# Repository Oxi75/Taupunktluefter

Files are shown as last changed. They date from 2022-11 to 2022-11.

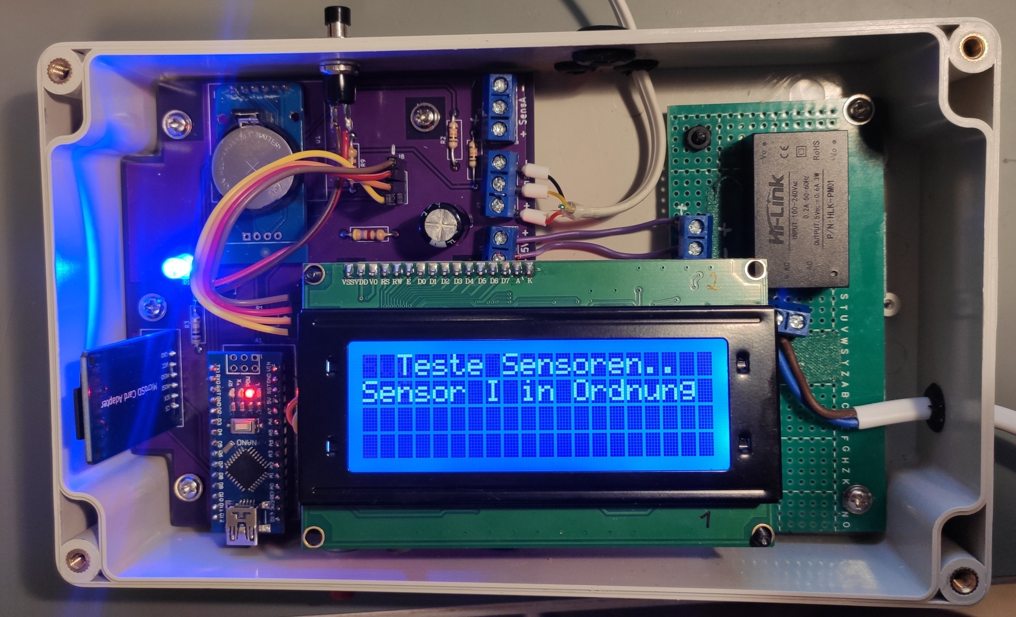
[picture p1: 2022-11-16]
documentation/Housing2.jpg

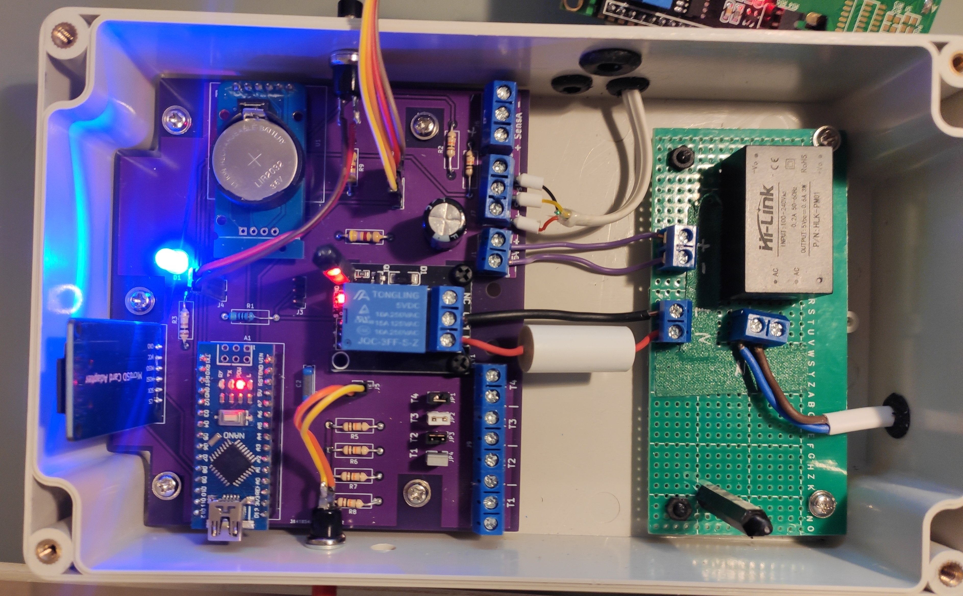
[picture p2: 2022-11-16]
documentation/Housing.jpg

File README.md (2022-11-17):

Dies ist meine erweiterte Version vom Taupunktlüfter mit Logging-Funktion der Maker Media GmbH.
Das Original mit den wichtigsten Fragen rund um den Taupunktlüfter beantwortet eine **[FAQ](https://heise.de/-6526328)**. Die vollständigen Artikel zum Projekt gibt es in der **[Make-Ausgabe 1/22 ab Seite 22](https://www.heise.de/select/make/2022/1/2135511212557842576)** und in der **[Make-Ausgabe 2/22 ab Seite 82](https://www.heise.de/select/make/2022/2/2204711461516715363)** zu lesen.

Das Original Github Projekt liegt hier: https://github.com/MakeMagazinDE/Taupunktluefter

# Taupunktlüfter mit Datenlogger V3.0

* Unterstützung von bis zu vier Tür-Sensoren. D.h. wenn der entsprechende Sensor
anzeigt, dass die Tür nicht geschlossen ist, springt auch der Lüfter nicht an.
Als Sensoren können einfache Schließer (z.B. Magnetschalter) zum Einsatz kommen.
Schalter geschlossen, bedeutet Tür geschlossen.
Auf dem PCB sind Jumper vorgesehen um die Schalter zu überbrücken.
Wird eine offene Tür erkannt, so geht einerseits die Hinweis-LED permanent an,
andererseits wird eine entsprechende Information auf dem Display ausgegeben.
* Display-Auto-Off
Das Backlight des Displays wird nach einer bestimmten Zeit deaktiviert. Um es wieder zu
aktivieren, ist ein dafür vorgesehener Taster zu drücken.
* Umbenennung der Sensoren
„Sensor 1“ und „Sensor 2“ wurden umbenannt nach „Sensor I“ für „Sensor innen“ und
„Sensor A“ für „Sensor außen“.
* Erstellung von Schaltplan und Layout in KiCad 6.0;
Platine passend für Gehäuse Maße: 200 x 120 x 57 mm Deckel klar
https://www.ebay.de/itm/312566082994?var=611287841843

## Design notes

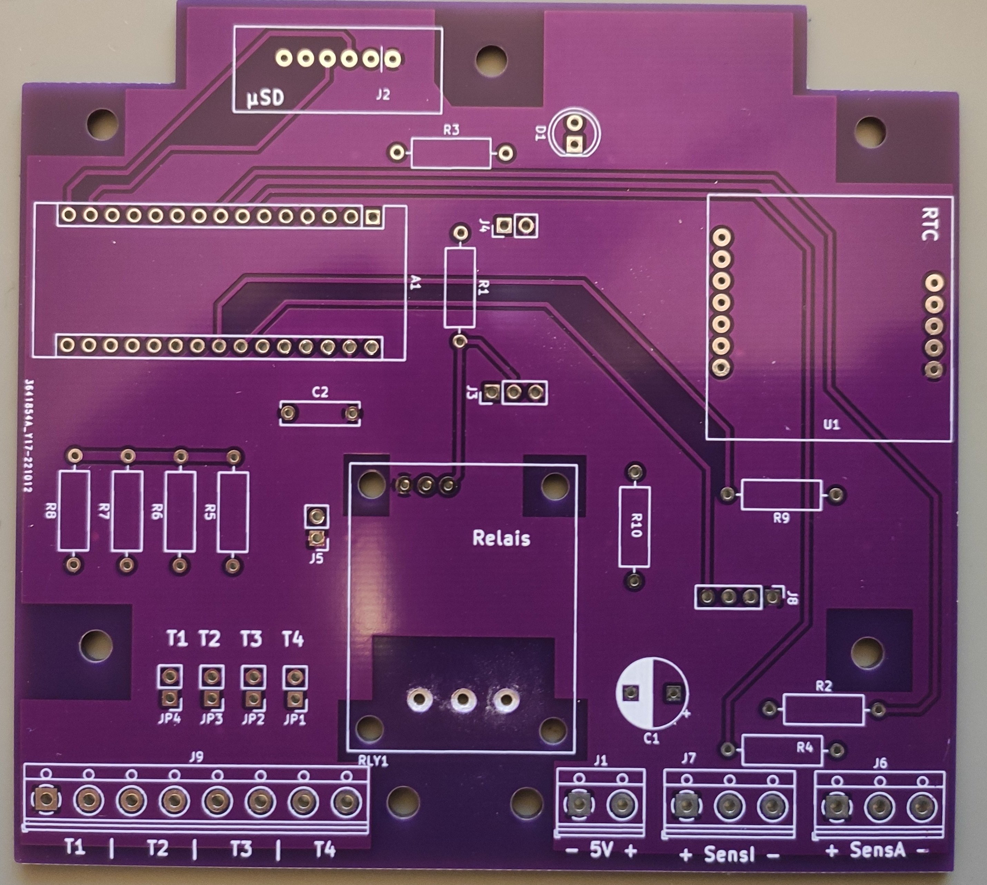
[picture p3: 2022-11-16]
documentation/Taupunkt_PCB_Front.jpg

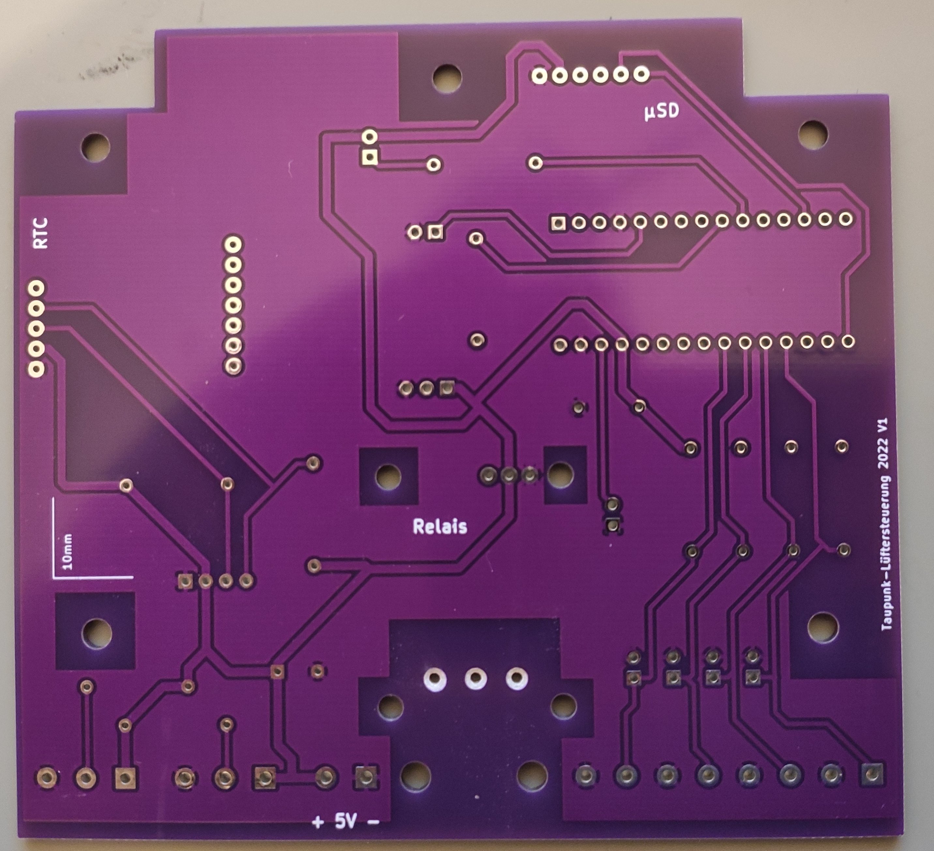
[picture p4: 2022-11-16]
documentation/Taupunkt_PCB_Back.jpg

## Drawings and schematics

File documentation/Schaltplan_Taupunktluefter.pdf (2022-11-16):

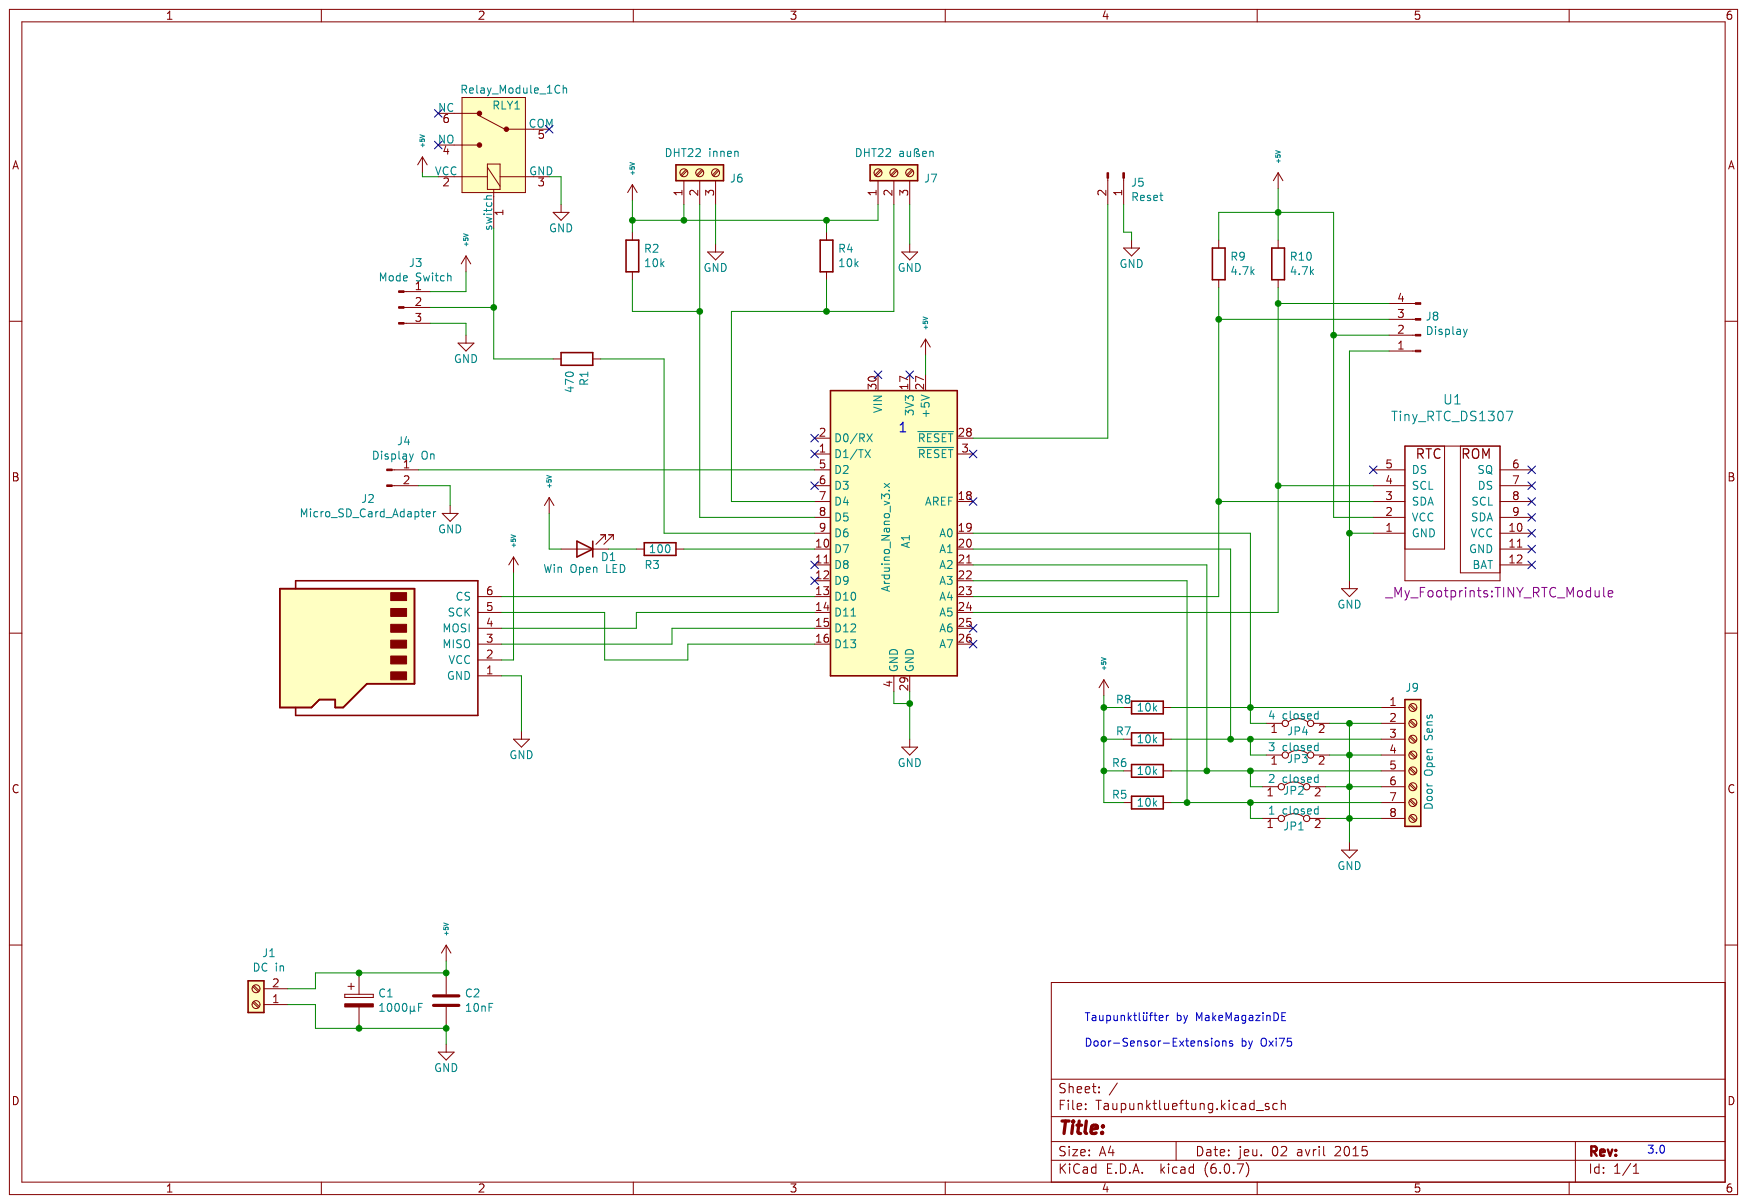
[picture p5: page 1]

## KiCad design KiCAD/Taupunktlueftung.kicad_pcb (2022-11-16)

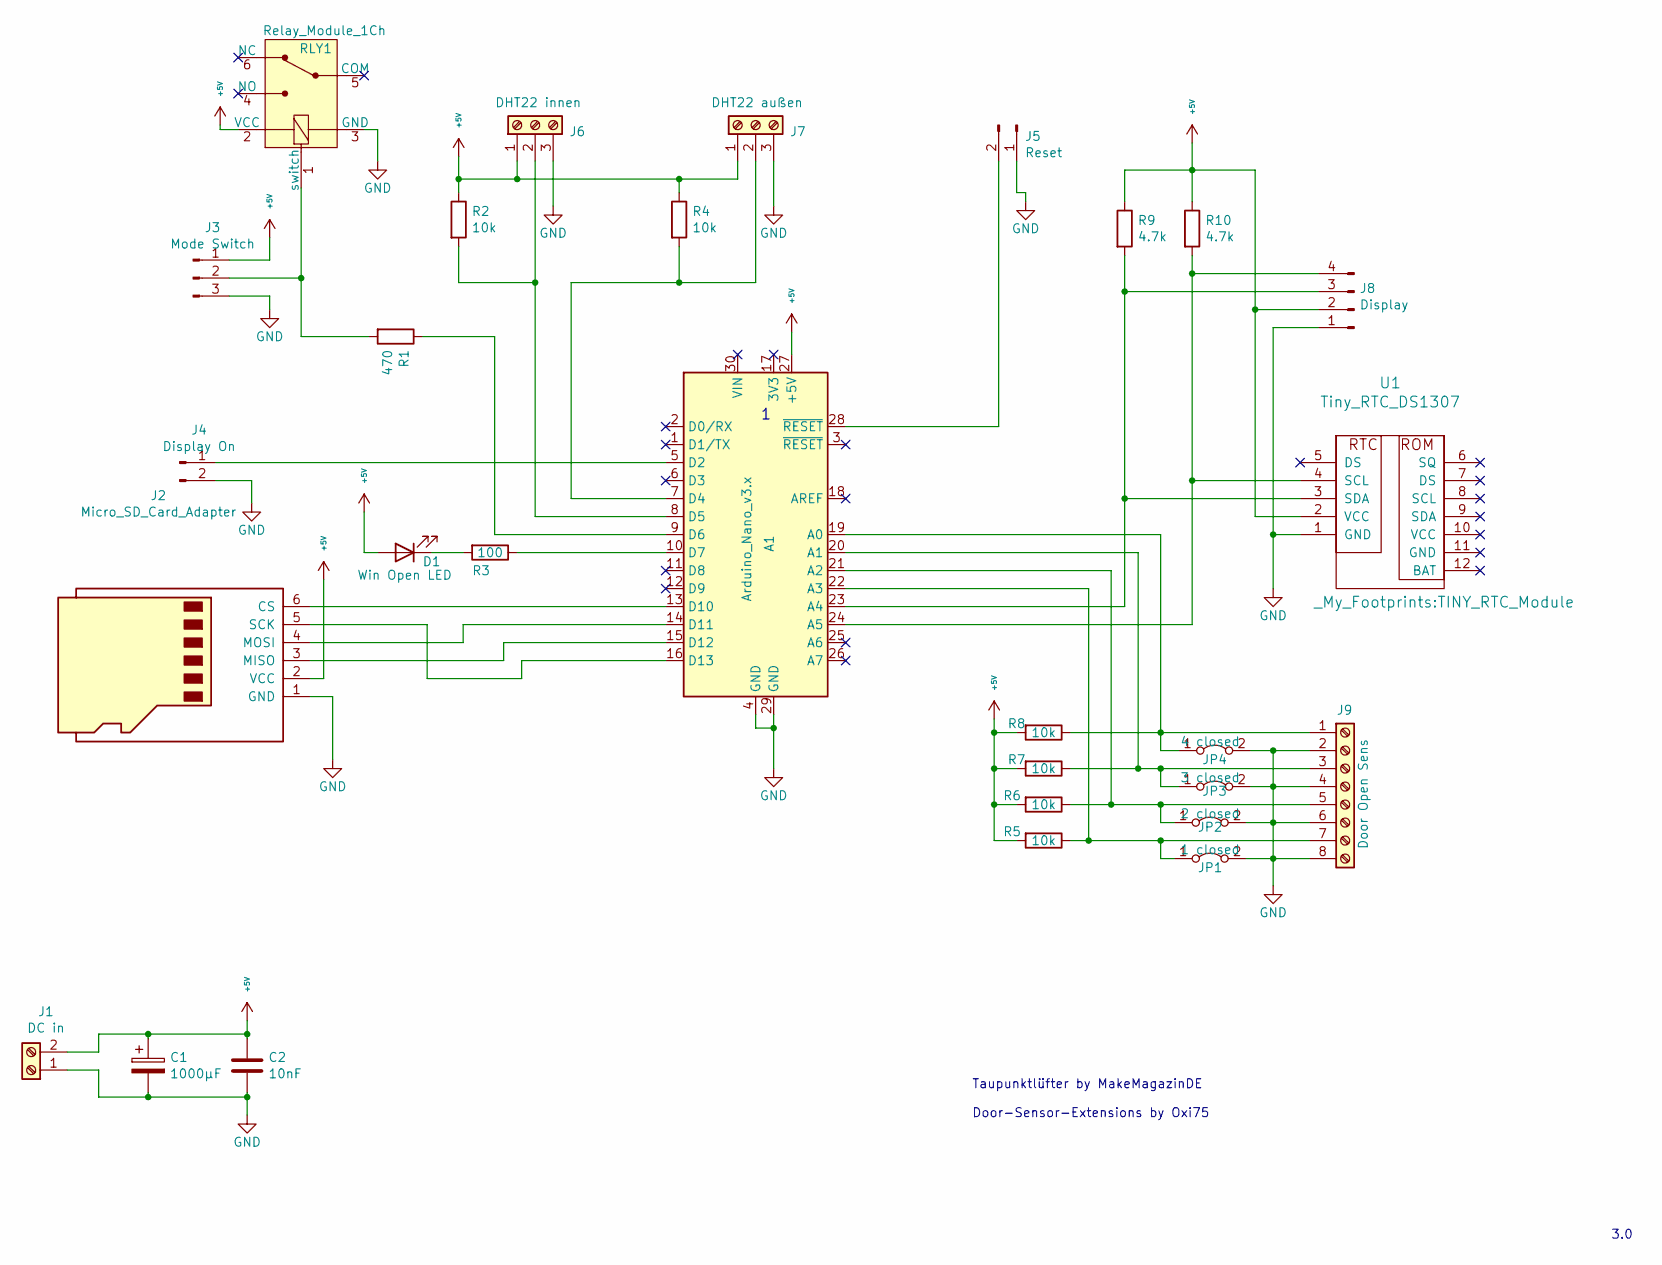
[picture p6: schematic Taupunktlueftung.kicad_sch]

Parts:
A1: Arduino_Nano_v3.x; Arduino_Nano
C1: 1000µF; CP_Radial_D8.0mm_P5.00mm
C2: 10nF; C_Rect_L9.0mm_W2.5mm_P7.50mm_MKT
D1: Win Open LED; LED_D5.0mm
J1: DC in; TerminalBlock_RND_205-00012_1x02_P5.00mm_Horizontal
J2: Micro_SD_Card_Adapter; MicroSD-Module_upright
J3: Mode Switch; PinHeader_1x03_P2.54mm_Vertical
J4: Display On; PinHeader_1x02_P2.54mm_Vertical
J5: Reset; PinHeader_1x02_P2.54mm_Vertical
J6: DHT22 innen; TerminalBlock_RND_205-00013_1x03_P5.00mm_Horizontal
J7: DHT22 außen; TerminalBlock_RND_205-00013_1x03_P5.00mm_Horizontal
J8: Display; PinHeader_1x04_P2.54mm_Vertical
J9: Door Open Sens; TerminalBlock_RND_205-00018_1x08_P5.00mm_Horizontal
JP1: 1 closed; PinHeader_1x02_P2.54mm_Vertical
JP2: 2 closed; PinHeader_1x02_P2.54mm_Vertical
JP3: 3 closed; PinHeader_1x02_P2.54mm_Vertical
JP4: 4 closed; PinHeader_1x02_P2.54mm_Vertical
R1: 470; R_Axial_DIN0309_L9.0mm_D3.2mm_P12.70mm_Horizontal
R2, R4, R5, R6, R7, R8: 10k; R_Axial_DIN0309_L9.0mm_D3.2mm_P12.70mm_Horizontal
R3: 100; R_Axial_DIN0309_L9.0mm_D3.2mm_P12.70mm_Horizontal
R9, R10: 4.7k; R_Axial_DIN0309_L9.0mm_D3.2mm_P12.70mm_Horizontal
RLY1: Relay_Module_1Ch
U1: Tiny_RTC_DS1307; TINY_RTC_Module

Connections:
+5V: A1.27 (+5V), C1.1, C2.1, D1.2 (A), J1.2, J2.2 (VCC), J3.1, J6.1, J7.1, J8.2, R2.1, R4.1, R5.2, R6.2, R7.2, R8.2, R9.1, R10.1, RLY1.2 (VCC), U1.2 (VCC)
GND: A1.4 (GND), A1.29 (GND), C1.2, C2.2, J1.1, J2.1 (GND), J3.3, J4.2, J5.1, J6.3, J7.3, J8.1, J9.2, J9.4, J9.6, J9.8, JP1.2 (B), JP2.2 (B), JP3.2 (B), JP4.2 (B), RLY1.3 (GND), U1.1 (GND)
unnamed: A1.5 (D2), J4.1
unnamed: A1.7 (D4), J7.2, R4.2
unnamed: A1.8 (D5), J6.2, R2.2
unnamed: A1.9 (D6), R1.1
unnamed: A1.10 (D7), R3.1
unnamed: A1.13 (D10), J2.6 (CS)
unnamed: A1.14 (D11), J2.4 (MOSI)
unnamed: A1.15 (D12), J2.3 (MISO)
unnamed: A1.16 (D13), J2.5 (SCK)
unnamed: A1.19 (A0), J9.1, JP4.1 (A), R8.1
unnamed: A1.20 (A1), J9.3, JP3.1 (A), R7.1
unnamed: A1.21 (A2), J9.5, JP2.1 (A), R6.1
unnamed: A1.22 (A3), J9.7, JP1.1 (A), R5.1
unnamed: A1.23 (A4), J8.3, R9.2, U1.3 (SDA)
unnamed: A1.24 (A5), J8.4, R10.2, U1.4 (SCL)
unnamed: A1.28 (~RESET), J5.2
unnamed: D1.1 (K), R3.2
unnamed: J3.2, R1.2, RLY1.1 (switch)

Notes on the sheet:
3.0
Taupunktlüfter by MakeMagazinDE Door-Sensor-Extensions by Oxi75

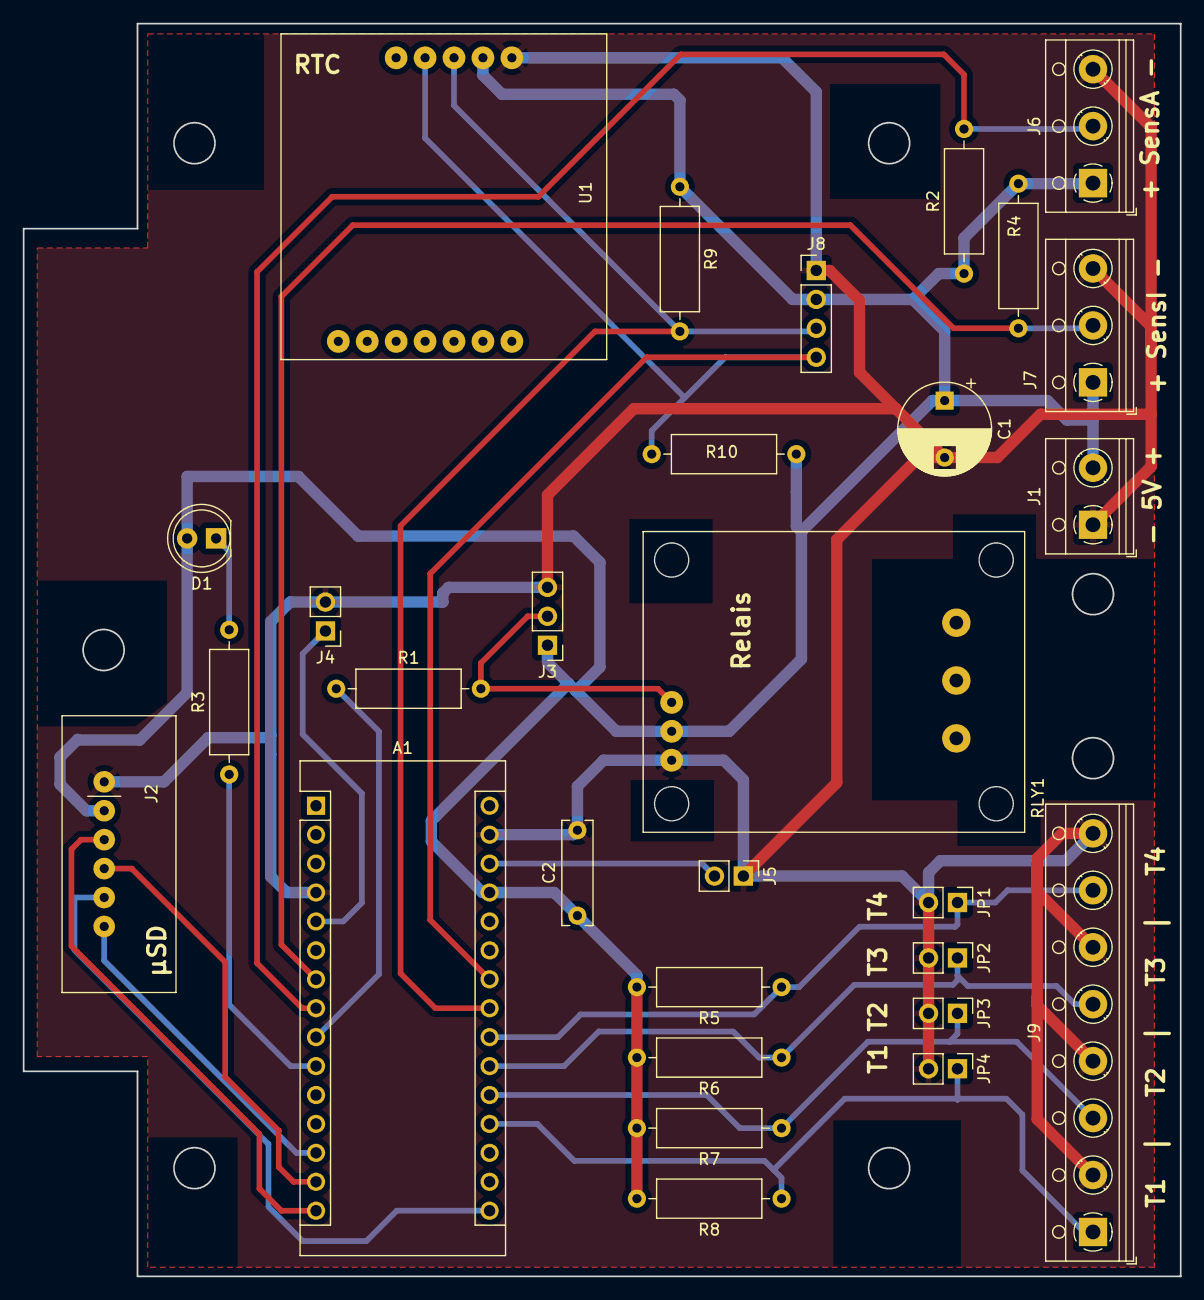
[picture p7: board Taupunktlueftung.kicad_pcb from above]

Board: 2 copper layers, 101.6 x 110.0 mm, 29 parts (0 on the bottom side), 20 nets.

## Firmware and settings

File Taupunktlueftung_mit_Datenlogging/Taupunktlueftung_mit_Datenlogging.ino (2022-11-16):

//////////////////////////////////////////////////////////////////////////////
// Das Taupunkt-Lüftungssystem
// mit Datenlogging
//
// veröffentlicht in der MAKE 1/2022 und 2/2022
//
// Ulrich Schmerold
// 3/2022
//////////////////////////////////////////////////////////////////////////////
// TUER-Sensor and Power saving Extensions by Andreas Schmack 9/2022
//////////////////////////////////////////////////////////////////////////////
#define Software_version "Version: 3.0"

// Dieser Code benötig zwingend die folgenden Libraries:
#include "DHT.h"
#include <Wire.h>
#include <LiquidCrystal_I2C.h>
#include <avr/wdt.h>
#include <DS1307RTC.h>
#include <SD.h>
#include <SPI.h>

tmElements_t tm;

#define RELAIPIN 6     // Anschluss des LüfterRelais
#define DHTPIN_I 4     // Datenleitung für den DHT Sensor I (innen)
#define DHTPIN_A 5     // Datenleitung für den DHT Sensor A (außen)

#define TUER1PIN A3    // Tür1-Kontakt 
#define TUER2PIN A1    // Tür1-Kontakt 
#define TUER3PIN A2    // Tür1-Kontakt 
#define TUER4PIN A0    // Tür1-Kontakt 
#define OFFEN HIGH     // Tür ist offen
#define ZU    LOW      // Tür ist zu
#define TUERLEDPIN 7   // Zeigt an, dass mindestens eine Tür offen ist

#define TFTANPIN 2     // TFT Backlight on
#define TFTEINZEIT 20000 // TFT bleibt nach Aktivierung ms an

#define RELAIS_EIN HIGH
#define RELAIS_AUS LOW
#define LED_EIN LOW
#define LED_AUS HIGH
#define TFT_EIN LOW
#define TFT_AUS HIGH

bool rel;
bool fehler = true;

#define DHTTYPE_I DHT22   // DHT 22 
#define DHTTYPE_A DHT22   // DHT 22  

// ***************************   Korrekturwerte der einzelnen Sensorwerten.  ***************
#define Korrektur_t_1  -3   // Korrekturwert Innensensor Temperatur
#define Korrektur_t_2  -4   // Korrekturwert Außensensor Temperatur
#define Korrektur_h_1  0    // Korrekturwert Innensensor Luftfeuchtigkeit
#define Korrektur_h_2  0    // Korrekturwert Außensensor Luftfeuchtigkeit
//******************************************************************************************

#define SCHALTmin   5.0   // minimaler Taupuntunterschied, bei dem das Relais schaltet
#define HYSTERESE   1.0   // Abstand von Ein- und Ausschaltpunkt
#define TEMP1_min  10.0   // Minimale Innentemperatur, bei der die Lüftung aktiviert wird
#define TEMP2_min -10.0   // Minimale Außentemperatur, bei der die Lüftung aktiviert wird

DHT dht1(DHTPIN_I, DHTTYPE_I);  //Der Innensensor wird ab jetzt mit dht1 angesprochen
DHT dht2(DHTPIN_A, DHTTYPE_A);  //Der Außensensor wird ab jetzt mit dht2 angesprochen

LiquidCrystal_I2C lcd(0x27,20,4); // LCD Display I2C Addresse und Displaygröße setzen

uint32_t TFT_AN_ZEIT;   //Zeitstempel für TFT-Backlight-Abschaltung

//++++++++++++++++++++++++++++++++ Variablen für das Datenlogging ***************************************
#define Headerzeile F("Datum|Zeit;Temperatur_S1;Feuchte_H1;Taupunkt_1;Temperatur_S2;Feuchte_H2;Taupunkt_2;Luefter_Ein/Aus;Laufzeit_Luefter;")

#define logFileName F("Luefter1.csv")  // Name der Datei zum Abspeichern der Daten (Dateinamen-Format: 8.3)!!!!
#define LogInterval 10                   // Wie oft werden die Messwerte aufgezeichnet ( 5 = alle 5 Minuten)

bool logging = true;                    // Sollen die Daten überhaupt protokolliert werden?
String LogData = "" ;                   // Variable zum Zusammensetzen des Logging-Strings.
char stamp[17];                         // Variable für den Zeitstempel.
unsigned int LuefterStart = 0;          // Wann wurde der Lüfter eingeschaltet?
unsigned int LuefterLaufzeit = 0;       // Wie lange lief der Lüfter?
char StrLuefterzeit[6];                 // Lüfterlaufzeit als String zur weiteren Verwendung.
uint8_t Today = 0;                      // Das heutige Datum (nur Tag), zur Speicherung bei Tageswechsel.
bool Tageswechsel=false;
//********************************************************************************************************

void setup()
{
    wdt_enable(WDTO_8S); // Watchdog timer auf 8 Sekunden stellen

    pinMode(RELAIPIN, OUTPUT);          // Relaispin als Output definieren
    digitalWrite(RELAIPIN, RELAIS_EIN); // Relais während dem Start zur Kontrolle einschalten

    pinMode(TUERLEDPIN, OUTPUT);        // LED-Pin als Output definieren
    digitalWrite(TUERLEDPIN, LED_EIN);  // LED während dem Starten einschalten

    pinMode(TUER1PIN, INPUT);           // Türkontakt1-Pin als Input definieren
    pinMode(TUER2PIN, INPUT);           // Türkontakt2-Pin als Input definieren
    pinMode(TUER3PIN, INPUT);           // Türkontakt3-Pin als Input definieren
    pinMode(TUER4PIN, INPUT);           // Türkontakt4-Pin als Input definieren
    
    pinMode(TFTANPIN, INPUT_PULLUP);    // Anmerkung: Backlight soll per default aus sein

    lcd.init();         //LCD initialisieren
    lcd.clear();        //LCD löschen
    lcd.backlight();    //LCD Backlight während der Startphase einschalten

    wdt_reset();        // Watchdog zurücksetzen

    //--------------------- Logging ------------------------------------------------------------------------------------
    if (logging == true)
    {
        lcd.setCursor(0,1);            // Curser auf Zeile 1, 2. Zeichen
        lcd.print(Software_version);   // Welche Softwareversion läuft gerade
        RTC_start();                   // RTC-Modul testen. Wenn Fehler, dann kein Logging
        delay (4000);                  // Zeit um das Display zu lesen
        lcd.clear();                   // LCD wieder löschen
        wdt_reset();                   // Watchdog zurücksetzen
        test_SD();                     // SD-Karte suchen. Wenn nicht gefunden, dann kein Logging ausführen
        Today = tm.Day ;
    }
    
    //------------------------------------------------ Neustart aufzeichnen -------------------------------------
    if (logging == true) // kann sich ja geändert haben wenn Fehler bei RTC oder SD
    {
        make_time_stamp();
        File logFile = SD.open(logFileName, FILE_WRITE);
        logFile.print(stamp);
        logFile.println(F(": Neustart"));                    // Damit festgehalten wird, wie oft die Steuerung neu gestartet ist
        logFile.close();
     } //---------------------------------------------------------------------------------------------------------------------

    //---------------------- diverse Sonderzeichen definieren --------------------------------------------------
    //Anm.: Nicht ganz klar, warum kein lcd.write(223); verwendet wird um z.B. das Grad-Zeichen auszugeben
    byte Grad[8] = {B00111,B00101,B00111,B0000,B00000,B00000,B00000,B00000};      // Sonderzeichen ° definieren
    lcd.createChar(0, Grad);
    byte Strich[8] = {B00100,B00100,B00100,B00100,B00100,B00100,B00100,B00100};   // Sonderzeichen senkrechter Strich definieren    
    lcd.createChar(1, Strich);
    byte KleinUE[8] = {B10010, B00000, B10010, B10010, B10010, B10010, B01101, B00000};   // Sonderzeichen ü
    lcd.createChar(2, KleinUE);
    byte GrossUE[8] = {B10001, B00000, B10001, B10001, B10001, B10001, B01110, B00000};   // Sonderzeichen Ü
    lcd.createChar(3, GrossUE);

    //--------------------------- Sensoren starten ------------------------------------------------------
    dht1.begin(); // Sensoren starten
    dht2.begin();

    TFT_AN_ZEIT = millis();
    digitalWrite(RELAIPIN, RELAIS_AUS); // Relais ausschalten
}

// ----------------- Beginn Main-Loop --------------------------
void loop()
{
    LCD_EIN_AUS();  // Prüfen ob TFT Backlight aktiviert bzw. deaktiviert werden muss

    // Sensoren auslesen
    RTC.read(tm);
    float h1 = dht1.readHumidity()+Korrektur_h_1;       // Innenluftfeuchtigkeit auslesen und unter „h1“ speichern
    float t1 = dht1.readTemperature()+ Korrektur_t_1;   // Innentemperatur auslesen und unter „t1“ speichern
    float h2 = dht2.readHumidity()+Korrektur_h_2;       // Außenluftfeuchtigkeit auslesen und unter „h2“ speichern
    float t2 = dht2.readTemperature()+ Korrektur_t_2;   // Außentemperatur auslesen und unter „t2“ speichern

    if (fehler == true)  // Prüfen, ob gültige Werte von den Sensoren kommen
    {
        lcd.clear();
        lcd.setCursor(2,0);
        lcd.print(F("Teste Sensoren.."));
        fehler = false;
        if (isnan(h1) || isnan(t1) || h1 > 100 || h1 < 1 || t1 < -40 || t1 > 80 )  {
            // Serial.println(F("Fehler beim Auslesen vom 1. Sensor!"));
            lcd.setCursor(0,1);
            lcd.print(F("Fehler Sensor Innen"));
            fehler = true;
        } else {
            lcd.setCursor(0,1);
            lcd.print(F("Sensor 1 in Ordnung"));
        }

        LCD_EIN_AUS();  // Prüfen ob TFT Backlight aktiviert bzw. deaktiviert werden muss
        delay(2000);  // Zeit um das Display zu lesen
        LCD_EIN_AUS();  // Prüfen ob TFT Backlight aktiviert bzw. deaktiviert werden muss

        if (isnan(h2) || isnan(t2) || h2 > 100 || h2 < 1 || t2 < -40 || t2  > 80) 
        {
            // Serial.println(F("Fehler beim Auslesen vom 2. Sensor!"));
            lcd.setCursor(0,2);
            lcd.print(F("Fehler Sensor 2"));
            fehler = true;
        } else {
            lcd.setCursor(0,2);
            lcd.print(F("Sensor 2 in Ordnung"));
        }

        delay(2000);  // Zeit um das Display zu lesen
    }
    if (isnan(h1) || isnan(t1) || isnan(h2) || isnan(t2)) fehler = true;

    LCD_EIN_AUS();  // Prüfen ob TFT Backlight aktiviert bzw. deaktiviert werden muss

    if (fehler == true) {
        digitalWrite(RELAIPIN, RELAIS_AUS); // Relais ausschalten
        lcd.setCursor(0,3);
        lcd.print(F("CPU Neustart....."));
        while (1);  // Endlosschleife um das Display zu lesen und die CPU durch den Watchdog neu zu starten
    }
    wdt_reset();  // Watchdog zurücksetzen


    /**************************************************************************/
    /* Türkontakte prüfen. Wenn eine Tür geöffnet, System nicht aktivieren!
    /**************************************************************************/
    int TUER1 = digitalRead(TUER1PIN);                 //Status Tür 1
    int TUER2 = digitalRead(TUER2PIN);                 //Status Tür 2
    int TUER3 = digitalRead(TUER3PIN);                 //Status Tür 3
    int TUER4 = digitalRead(TUER4PIN);                 //Status Tür 4
    int TUERSTATUS;

    lcd.clear();
    LCD_EIN_AUS();  // Prüfen ob TFT Backlight aktiviert bzw. deaktiviert werden muss
    lcd.setCursor(0,0);
    lcd.print("T");         //Türkontakte:
    lcd.write((uint8_t)3);  //
    lcd.print("rkontakte:");

    if ((TUER1 == OFFEN) || (TUER2 == OFFEN) || (TUER3 == OFFEN) || (TUER4 == OFFEN))
    {
      TUERSTATUS = OFFEN;
      digitalWrite(TUERLEDPIN, LED_EIN);  // Signal-LED einschalten

      lcd.setCursor(0,1);
      lcd.print(" offen: ");
      if (TUER1) lcd.print("1  ");
      if (TUER2) lcd.print("2  ");
      if (TUER3) lcd.print("3  ");
      if (TUER4) lcd.print("4");

      lcd.setCursor(0,2);
      lcd.print(" zu:    ");
      if (!TUER1) lcd.print("1  ");
      if (!TUER2) lcd.print("2  ");
      if (!TUER3) lcd.print("3  ");
      if (!TUER4) lcd.print("4");

      delay(2000);  // Zeit um das Display zu lesen
    }
    else
    {
       TUERSTATUS = ZU;
       digitalWrite(TUERLEDPIN, LED_AUS);  // Signal-LED einschalten
       //lcd.setCursor(0,2);
       //lcd.print("  Alle geschlossen");    //Alle geschlossen
       //delay(2000);  // Zeit um das Display zu lesen
    }

    wdt_reset();  // Watchdog zurücksetzen


//**** Taupunkte errechnen********
    float Taupunkt_1 = taupunkt(t1, h1);   //Taupunkt innen
    float Taupunkt_2 = taupunkt(t2, h2);   //Taupunkt außen

    // Werteausgabe auf dem I2C-Display
    lcd.clear();
    LCD_EIN_AUS();  // Prüfen ob TFT Backlight aktiviert bzw. deaktiviert werden muss
    lcd.setCursor(0,0);
    lcd.print(F("SI: "));
    lcd.print(t1);
    lcd.write((uint8_t)0); // Sonderzeichen °C
    lcd.write(('C'));
    lcd.write((uint8_t)1); // Sonderzeichen |
    lcd.print(h1);
    lcd.print(F(" %"));

    lcd.setCursor(0,1);
    lcd.print(F("SA: "));
    lcd.print(t2);
    lcd.write((uint8_t)0); // Sonderzeichen °C
    lcd.write(('C'));
    lcd.write((uint8_t)1); // Sonderzeichen |
    lcd.print(h2);
    lcd.print(F(" %"));

    lcd.setCursor(0,2);
    lcd.print(F("Taupunkt I: "));
    lcd.print(Taupunkt_1);
    lcd.write((uint8_t)0); // Sonderzeichen °C
    lcd.write(('C'));

    lcd.setCursor(0,3);
    lcd.print(F("Taupunkt A: "));
    lcd.print(Taupunkt_2);
    lcd.write((uint8_t)0); // Sonderzeichen °C
    lcd.write(('C'));

    delay(5000); // Zeit um das Display zu lesen
    wdt_reset(); // Watchdog zurücksetzen

    lcd.clear();
    lcd.setCursor(0,0);

    float DeltaTP = Taupunkt_1 - Taupunkt_2;

    if (DeltaTP > (SCHALTmin + HYSTERESE)) rel = true;    //Taupunkt-Unterschied überhalb Schaltschwelle  => Einschalten
    if (DeltaTP < (SCHALTmin)) rel = false;               //Taupunkt-Unterschied unterhalb Schaltschwelle => Ausschalten
    if (t1 < TEMP1_min) rel = false;                      //Temperatur kleiner Minimal-Temperatur => Ausschalten
    if (t2 < TEMP2_min) rel = false;                      //Temperatur kleiner Minimal-Temperatur => Ausschalten
    if (TUERSTATUS == OFFEN) rel = false;                 //Tür(en) nicht geschlossen => Ausschalten

    if (rel == true)
    {
        digitalWrite(RELAIPIN, RELAIS_EIN); // Relais einschalten
        lcd.print("L");         //Lüftung: AN
        lcd.write((uint8_t)3);  // ü
        lcd.print("ftung: AN");
        if (LuefterStart <=0 && logging == true) {
            LuefterStart = tm.Hour*60 + tm.Minute;
        }
    } else {
        digitalWrite(RELAIPIN, RELAIS_AUS); // Relais ausschalten
        lcd.print("L");         //Lüftung: AUS
        lcd.write((uint8_t)3);  // ü
        lcd.print("ftung : AUS");
        if( LuefterStart > 0 && logging == true) {
            LuefterLaufzeit += (tm.Hour*60 + tm.Minute - LuefterStart);
            LuefterStart = 0;
        }
    }

    LCD_EIN_AUS();  // Prüfen ob TFT Backlight aktiviert bzw. deaktiviert werden muss
    lcd.setCursor(0,1);
    lcd.print(F("Delta TP: "));
    lcd.print(DeltaTP);
    lcd.write((uint8_t)0); // Sonderzeichen °C
    lcd.write('C');

    make_time_stamp();
    lcd.setCursor(0,3);
    lcd.print(stamp);
    lcd.setCursor(0,2);
    if (logging == true)lcd.print(F("Logging: AN"));
    else lcd.print(F("Logging: AUS"));

    delay(4000);   // Wartezeit zwischen zwei Messungen
    wdt_reset();   // Watchdog zurücksetzen

//--------------------------------------------logging-----------------------------------------------------
    if (logging == true)
    {
        if  ( Today  != tm.Day)                                                     // Tageswechsel ==> Lüfterzeit abspeichern
        {
            Tageswechsel = true;                                                    // ==> Sofort speichern (siehe SD.ino) ==> Nicht erst wenn LogIntervall abgelaufen ist
            if (LuefterStart > 0 ) LuefterLaufzeit += (1440 - LuefterStart);       // ==>Lüfter läuft gerade
            snprintf(StrLuefterzeit,sizeof(StrLuefterzeit),"%d;",LuefterLaufzeit);
            Today = tm.Day;
            LuefterLaufzeit = 0;
        } else {
            strcpy( StrLuefterzeit, "0;");     // Kein Tageswechsel, nur Platzhalter abspeichern
        }

        char buff[4];
        LogData="";
        dtostrf(t1, 2, 1, buff);
        LogData += buff ;
        LogData += ';';
        dtostrf(h1, 2, 1, buff);
        LogData += buff ;
        LogData += ';';
        dtostrf(Taupunkt_1, 2, 1, buff);
        LogData += buff ;
        LogData += ';';
        dtostrf(t2, 2, 1, buff);
        LogData += buff ;
        LogData += ';';
        dtostrf(h2, 2, 1, buff);
        LogData += buff;
        LogData += ';';
        dtostrf(Taupunkt_2, 2, 1, buff);
        LogData += buff;
        LogData += ';';
        if (rel == true) LogData +="1;";
        else LogData += "0;";
        LogData += StrLuefterzeit;

        save_to_SD(); // Daten auf die SD Karte speichern
    }
}
//---------------------------Ende Main-Loop ----------------------------------------------------------------




float taupunkt(float t, float r) {

    float a, b;

    if (t >= 0) {
        a = 7.5;
        b = 237.3;
    } else if (t < 0) {
        a = 7.6;
        b = 240.7;
    }

    // Sättigungsdampfdruck in hPa
    float sdd = 6.1078 * pow(10, (a*t)/(b+t));

    // Dampfdruck in hPa
    float dd = sdd * (r/100);

    // v-Parameter
    float v = log10(dd/6.1078);

    // Taupunkttemperatur (°C)
    float tt = (b*v) / (a-v);
    return { tt };
}


void software_Reset() // Startet das Programm neu, nicht aber die Sensoren oder das LCD
{
    asm volatile ("  jmp 0");
}


void LCD_EIN_AUS()
{
  static bool TFT_STATUS = TFT_AUS;
  uint32_t JETZT;
  uint32_t DIFF;
  
  JETZT = millis();                                           //aktuelle Systemzeit  
  if (digitalRead(TFTANPIN) == TFT_EIN) TFT_AN_ZEIT = JETZT;  //Wenn Display-Pin noch gedrückt ist, Zeitstempel zurück setzen  
  DIFF = JETZT - TFT_AN_ZEIT;                                 //Zeitdifferenz berechnen

  if ((DIFF < TFTEINZEIT) && (TFT_STATUS == TFT_AUS))         //Noch keine 10 Sek vergangen und TFT ausgeschaltet?
  {
    lcd.backlight();                                          //TFT Backlight einschalten
    TFT_STATUS = TFT_EIN;                                     //TFT Status merken
    TFT_AN_ZEIT = JETZT;                                      //die 10 Sekunden starten ab jetzt
  }

  if ((DIFF >= TFTEINZEIT) && (TFT_STATUS == TFT_EIN))        //Die Zeit ist abgelaufen, Display wieder ausschalten
  {
    lcd.noBacklight();                                        //TFT Backlight ausschalten
    TFT_STATUS = TFT_AUS;                                     //TFT Status merken
    attachInterrupt(digitalPinToInterrupt(TFTANPIN), INT_PINisr, LOW);  //Interrupt Wiedereinschalten des LCD-Backlight 
  }
}



// ********************************************************************
// ****  INT_PINisr()
// ****  is called on interrupt from ligth sensor
// ********************************************************************
void INT_PINisr(void)
/* ISR fuer Pin 2 */
{
  /* detach Interrupt, damit er nur einmal auftritt */
  detachInterrupt(digitalPinToInterrupt(TFTANPIN));
  //detachInterrupt(0);

  TFT_AN_ZEIT = millis();
}

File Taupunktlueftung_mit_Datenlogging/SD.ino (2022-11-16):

//////////////////////////////////////////////////////////////////////////////
// Das Taupunkt-Lüftungssystem 
// mit Datenlogging
// 
// Routinen zur Speicherung auf einer SD-Karte
//
// veröffentlicht in der MAKE 2/2022
//
// Ulrich Schmerold
// 3/2022
//////////////////////////////////////////////////////////////////////////////

File logFile;                    // Variable für die csv-Datei
#define CS_PIN 10                // An diesem Pin ist die CS-Leitung angeschlossen

unsigned long TimeDaten = 0;    // zur Berechnung, wann wieder gespeichert wird


void test_SD(){
  if (logging == true)
  {
    // --------- SD-Karte suchen  -------------------
  lcd.setCursor(0,0);
  lcd.print(F("Suche SD Karte.."));
  lcd.setCursor(2,1);

  if (!SD.begin(CS_PIN)){
   lcd.print(F("SD nicht gefunden!"));
   logging = false;
   } else {
    lcd.print(F("SD  gefunden"));
    if (not SD.exists(logFileName) )  
    {
      logFile = SD.open(logFileName, FILE_WRITE); 
      logFile.println(Headerzeile); // Header schreiben
      logFile.close();  
    }    
   }
   delay(3000);   // Zeit um das Display zu lesen
   wdt_reset();   // Watchdog zurücksetzen
  }
}


void save_to_SD()
{ 
  unsigned long t; 

 t = millis() / 60000;               
  if (  TimeDaten == 0 ) TimeDaten =  t;  

  // -------------------------  Sensorenwerte abspeichern ----------------------
  if (((TimeDaten + LogInterval) <= t)  or ( Tageswechsel ))
  {
    TimeDaten = t;
    Tageswechsel=false;
    test_SD();
    wdt_reset(); // Watchdog zurücksetzen
      lcd.clear();
      lcd.print(F("Speichere Datensatz"));   
      make_time_stamp();
      File logFile = SD.open(logFileName, FILE_WRITE);  // Oeffne Datei
      // Serial.print( stamp);  Serial.print( ';' + LogData );  Serial.println(Luefterzeit);
       logFile.print (stamp);
      logFile.println( ';' + LogData );
    logFile.close(); 
    delay(4000);
  } 
}

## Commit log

2022-11-16 Added KiCAD and Gerber Files Modification / Extension of original source code to support door sensors and display auto-off
    [Taupunktlueftung-B_Courtyard.gbr, Taupunktlueftung-B_Cu.gbr, Taupunktlueftung-B_Fab.gbr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]
2022-11-16 Added KiCAD and Gerber Files
    [Taupunktlueftung-B_Courtyard.gbr, Taupunktlueftung-B_Cu.gbr, Taupunktlueftung-B_Fab.gbr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]
2022-11-16 Extension of original source code to support door sensors and display auto-off
